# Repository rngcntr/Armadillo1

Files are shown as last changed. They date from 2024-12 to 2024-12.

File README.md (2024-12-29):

# Armadillo1

Image of the fully assembled keyboard

It all started with a [Talk by ink](https://media.ccc.de/v/gpn22-498-tastaturen-ein-drama-mit-10-fingern) at GPN22, which inspired me to build my own customized wireless split keyboard. This one is fitted to the exact size of my hands and features a 36 key layout.

## Layout

I used [ergopad](https://pashutk.com/ergopad/) to determine the exact poitions of my fingertips that feel most comfortable. Then, I replicated the resulting layout manually using [ergogen](https://ergogen.ceoloide.com/).

## Keymap

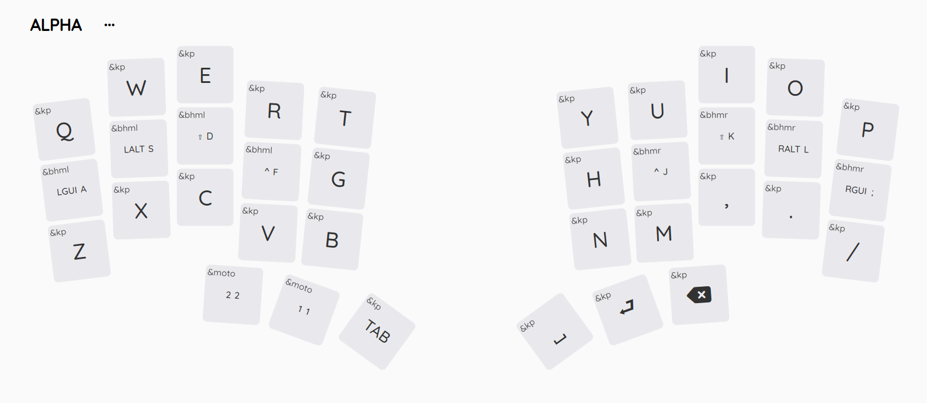
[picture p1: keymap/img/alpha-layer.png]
Alpha Layer Keymap


For more details, see the [keymap README](keymap/README.md).

## Controller & Display

[nice!nano](https://nicekeyboards.com/nice-nano/) and [nice!view](https://nicekeyboards.com/nice-view).

## Switches

Kailh MX Jade. They're clicky switches with an above-average activation force.

## Keycaps

Smolo Keycaps from [BeeKeeb](https://shop.beekeeb.com/product/smolo-low-profile-keycap/).

## Risers

Self-printed. The design is available on [MakerWorld](https://makerworld.com/en/models/809248#profileId-750244).

## Case

Self-printed. I'm not yet fully satisfied by the design, so it's not yet published. If you're actually interested to print one yourself, please poke me.

## Stands

Two [MagSafe Stands](https://de.ugreen.com/products/45378?_pos=28&_sid=3c43091c2&_ss=r) by Ugreen.

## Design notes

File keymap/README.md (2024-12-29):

# Armadillo Keymap

## How to use

### armadillo.keymap

The keymap configuration to include in your zmk config.

### armadillo-keymap-layout.json

You can import this file along with `armadillo.keymap` to [nickcoutsos.github.io](https://nickcoutsos.github.io/keymap-editor/) for a nice visualization of the layout. However, this tool doesn't pick up key combos. I visualized them by hand in the `symbols` layer by adding an icon between two keys. The combos are available in any layer.

Alpha Layer Layout
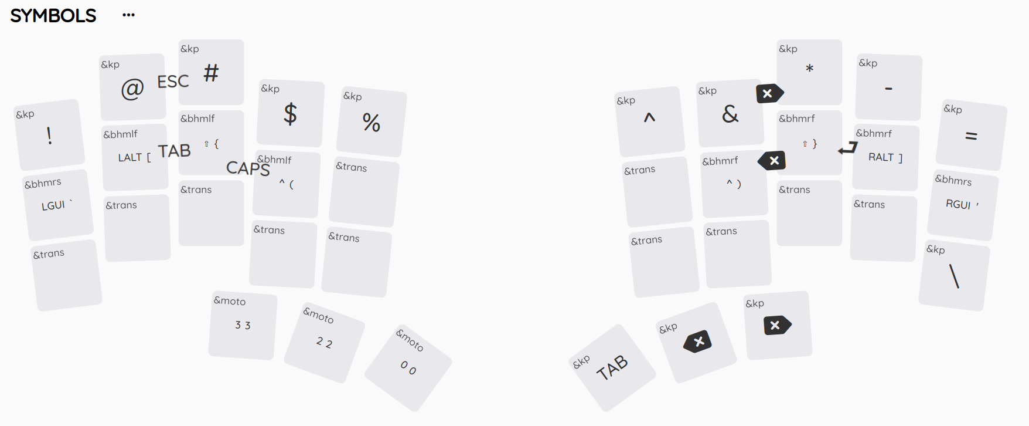
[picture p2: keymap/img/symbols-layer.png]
Symbols Layer Layout

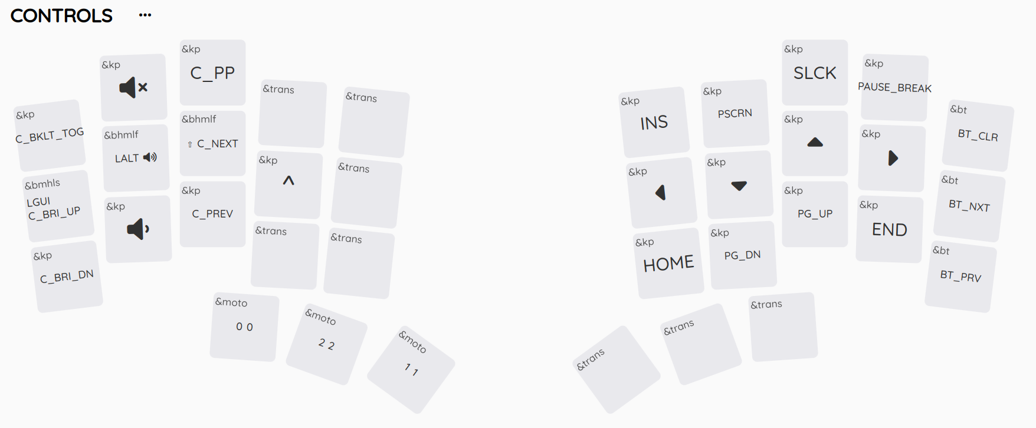
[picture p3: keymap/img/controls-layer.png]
Controls Layer Layout


The full `zmk` config can be found over at [rngcntr/zmk-config](https://github.com/rngcntr/zmk-config).
**WARNING**: The pin config differs from the one defined by the PCB by *one pin*, because the pin in question was damaged on my controller. I only noticed this once the PCB was already produced. Flashing this version without modification will cause one column to be ignored.

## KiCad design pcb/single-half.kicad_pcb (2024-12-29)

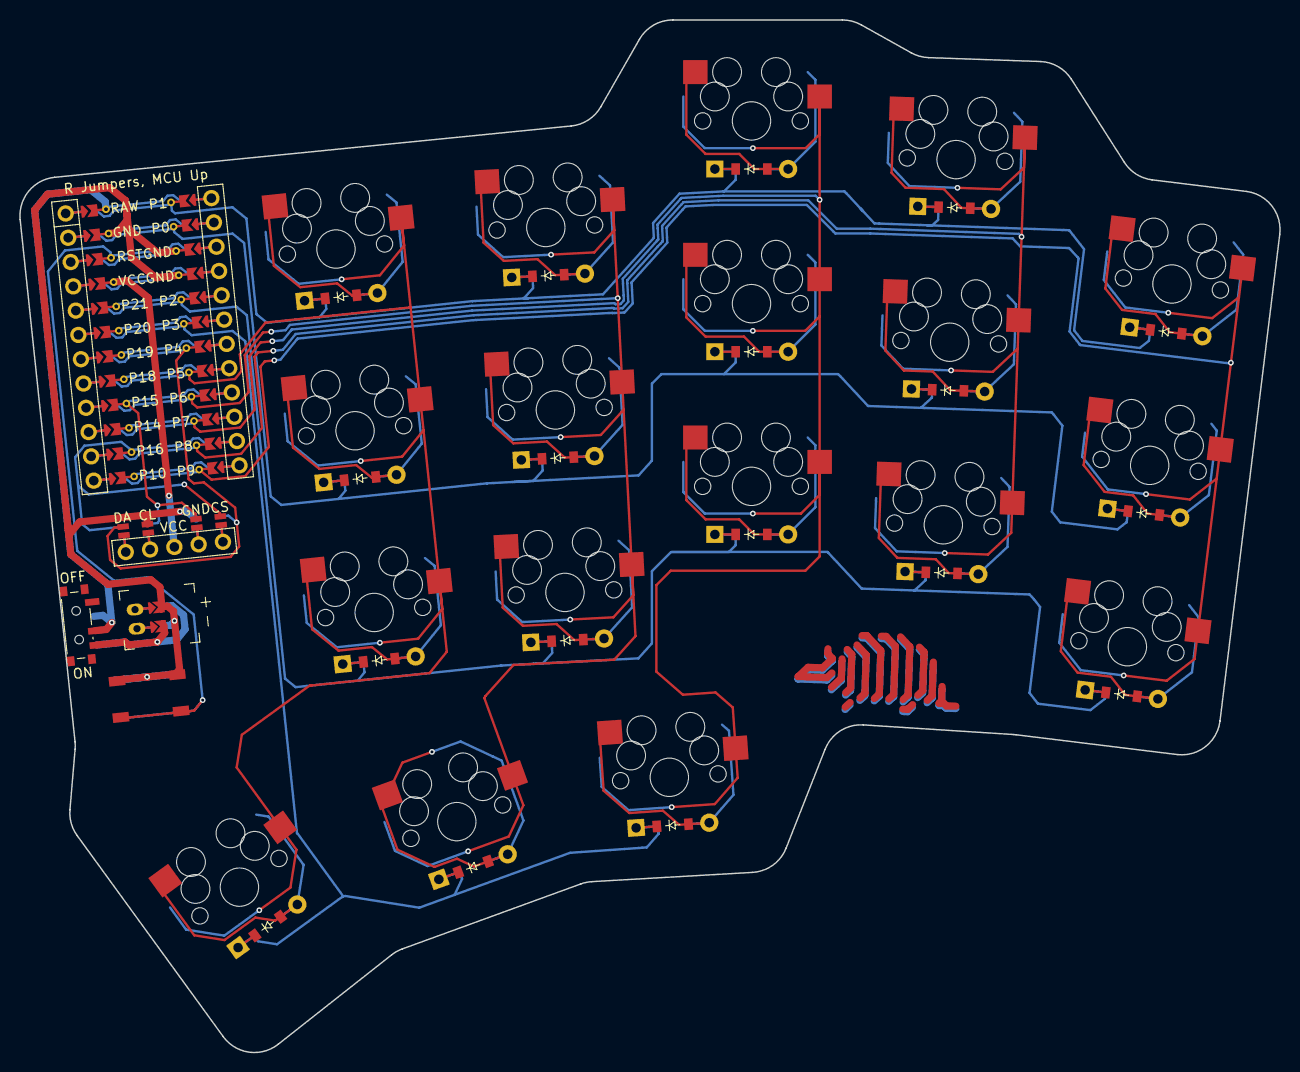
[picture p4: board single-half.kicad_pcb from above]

Board: 2 copper layers, 131.0 x 107.4 mm, 40 parts (0 on the bottom side), 40 nets.

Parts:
D1, D2, D3, D4, D5, D6, D7, D8, D9, D10, D11, D12, D13, D14, D15, D16, D17, D18: ComboDiode
DISP1: display_nice_view
JST1: battery_connector_jst_ph_2
MCU1: mcu_nice_nano
PWR1: power_switch_smd_side
S1, S2, S3, S4, S5, S6, S7, S8, S9, S10, S11, S12, S13, S14, S15, S16, S17, S18: MX

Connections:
BAT_P: JST1.1, PWR1.1, PWR1.3
DISP1_1: DISP1.1, DISP1.10, DISP1.23
DISP1_2: DISP1.2, DISP1.11, DISP1.22
DISP1_4: DISP1.4, DISP1.12, DISP1.21
DISP1_5: DISP1.5, DISP1.13, DISP1.20
GND: DISP1.15, DISP1.25, JST1.2, MCU1.103, MCU1.104, MCU1.123
JST1_1: JST1.11, JST1.21, JST1.31
JST1_2: JST1.12, JST1.22, JST1.32
P0: D2.1, D5.1, D8.1, D11.1, D14.1, MCU1.102
P1: D3.1, D6.1, D9.1, D12.1, D15.1, MCU1.101
P2: D1.1, D4.1, D7.1, D10.1, D13.1, MCU1.105
P3: D16.1, D17.1, D18.1, MCU1.106
P4: DISP1.14, DISP1.24, MCU1.107
P5: MCU1.108, S1.1, S2.1, S3.1, S16.1
P6: MCU1.109, S4.1, S5.1, S6.1, S17.1
P7: MCU1.110, S7.1, S8.1, S9.1, S18.1
P8: MCU1.111, S10.1, S11.1, S12.1
P9: MCU1.112, S13.1, S14.1, S15.1
P15: DISP1.16, DISP1.26, MCU1.116
P16: DISP1.17, DISP1.27, MCU1.114
RAW: MCU1.124, PWR1.2
VCC: DISP1.3, MCU1.121
index_bottom: D4.2, S4.2
index_home: D5.2, S5.2
index_top: D6.2, S6.2
inner_bottom: D1.2, S1.2
inner_home: D2.2, S2.2
inner_top: D3.2, S3.2
layer_cluster: D17.2, S17.2
middle_bottom: D7.2, S7.2
middle_home: D8.2, S8.2
middle_top: D9.2, S9.2
mod_cluster: D18.2, S18.2
pinky_bottom: D13.2, S13.2
pinky_home: D14.2, S14.2
pinky_top: D15.2, S15.2
ring_bottom: D10.2, S10.2
ring_home: D11.2, S11.2
ring_top: D12.2, S12.2
space_cluster: D16.2, S16.2
